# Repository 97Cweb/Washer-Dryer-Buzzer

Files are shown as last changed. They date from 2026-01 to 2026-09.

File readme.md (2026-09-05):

# Washer Dryer Buzzer

A thing to build to put buzzers back on the washing machine and dryer

V1 used a photoresistor on the washing machine
V2 uses 2 optocouplers to get the washing machine knob position.

Both use a non invasive current sensor for the dryer to get whether it is on or not.

You will also need a speaker module to get enough volume from the audio.

## Modules used:

* ARDUINO Nano 33 IOT

* 5PCS IR Infrared Slotted Optical Optocoupler Speed Measuring Sensor Module 3.3-5V for Arduino Also for Smart Robot Car Speed Measurement with Dupont Wire [Amazon](https://www.amazon.ca/dp/B09TK2H9NY)

* Non-Invasive Current Sensor (30A) [Canada Robotix](https://www.canadarobotix.com/products/246?variant=14423519297585)

* Stereo 20W Class D Audio Amplifier - MAX9744 [Adafruit 1752](https://www.adafruit.com/product/1752)

* 20W 4 Ohm Full Range Speaker - XS-GTF1027 [Adafruit 1732](https://www.adafruit.com/product/1732)

How to wire current sensor [link](https://www.engineersgarage.com/non-invasive-current-sensor-with-arduino/)

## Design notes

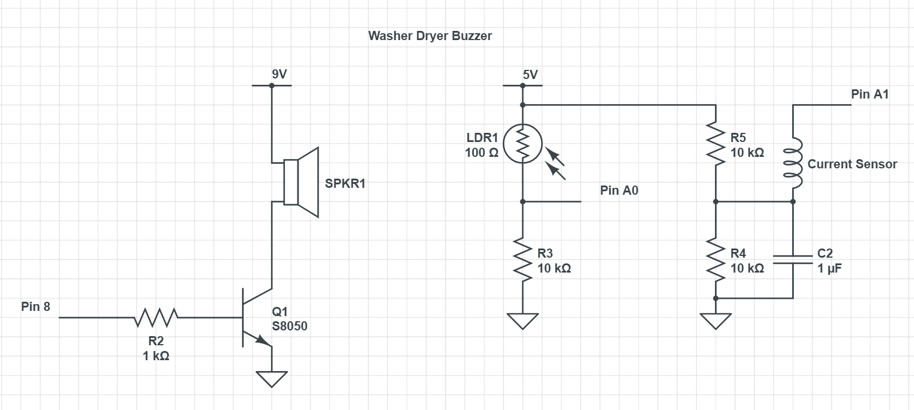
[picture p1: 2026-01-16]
washer dryer buzzer schematic.png

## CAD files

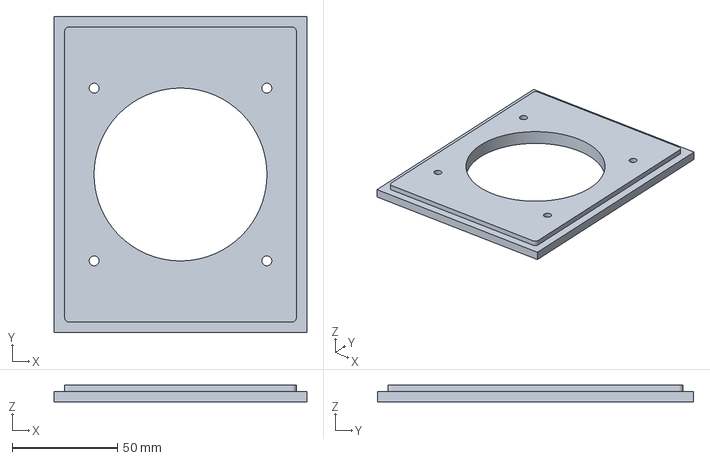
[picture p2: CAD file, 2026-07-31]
Box/lid-Body.3mf
120.0 x 150.0 x 8.00 mm

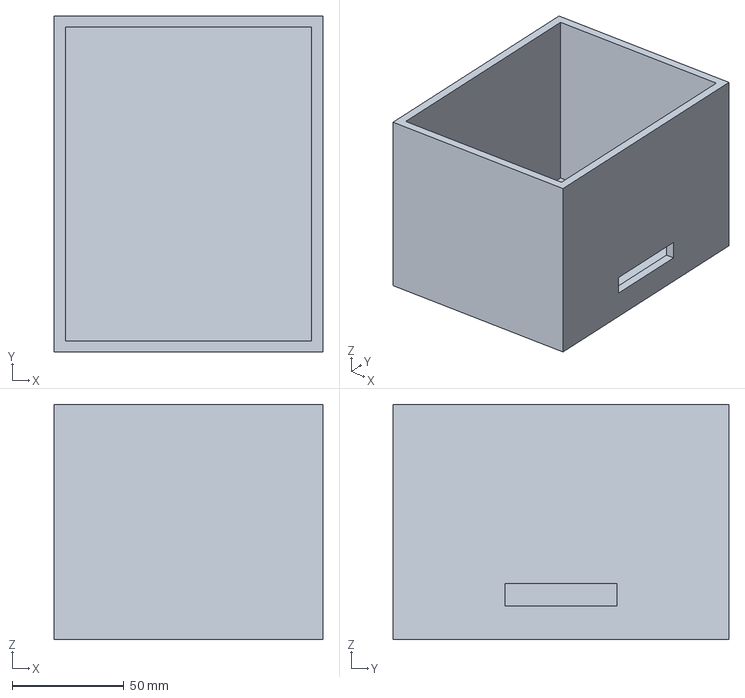
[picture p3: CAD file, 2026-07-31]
Box/box.FCStd
120.0 x 150.0 x 105.0 mm

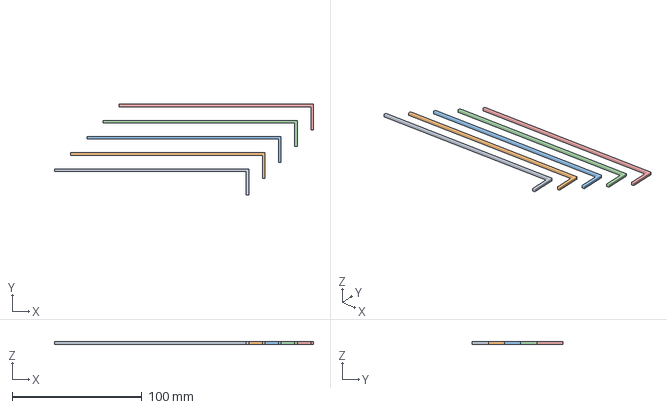
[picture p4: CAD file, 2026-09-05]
washer trip arm.3mf
200.0 x 70.0 x 2.00 mm

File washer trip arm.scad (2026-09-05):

difference(){
  cube([150,20,2]);
  cube([148,18,2]);
}

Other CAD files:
Box/lid.FCStd
Box/box-Body.3mf
washer trip arm.stl

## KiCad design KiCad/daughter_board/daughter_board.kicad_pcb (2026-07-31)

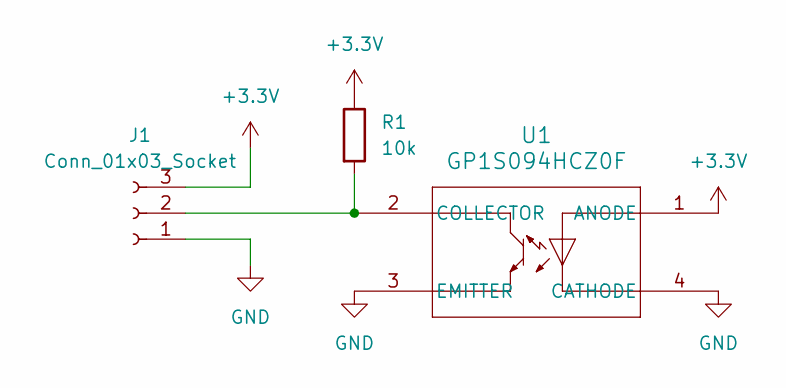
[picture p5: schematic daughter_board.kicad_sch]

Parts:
J1: Conn_01x03_Socket; JST_XA_B03B-XASK-1_1x03_P2.50mm_Vertical
R1: 10k; R_1206_3216Metric_Pad1.30x1.75mm_HandSolder
U1: GP1S094HCZ0F; TO_4HCZ0F_SHP

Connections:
+3.3V: J1.3, R1.1, U1.1 (ANODE)
GND: J1.1, U1.3 (EMITTER), U1.4 (CATHODE)
unnamed: J1.2, R1.2, U1.2 (COLLECTOR)

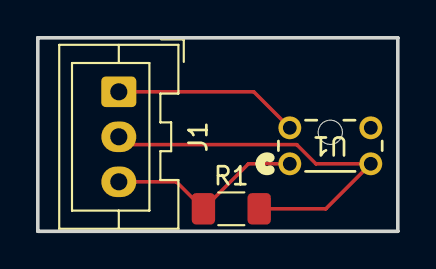
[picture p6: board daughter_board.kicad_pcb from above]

Board: 2 copper layers, 20.0 x 10.8 mm, 3 parts (0 on the bottom side), 3 nets.

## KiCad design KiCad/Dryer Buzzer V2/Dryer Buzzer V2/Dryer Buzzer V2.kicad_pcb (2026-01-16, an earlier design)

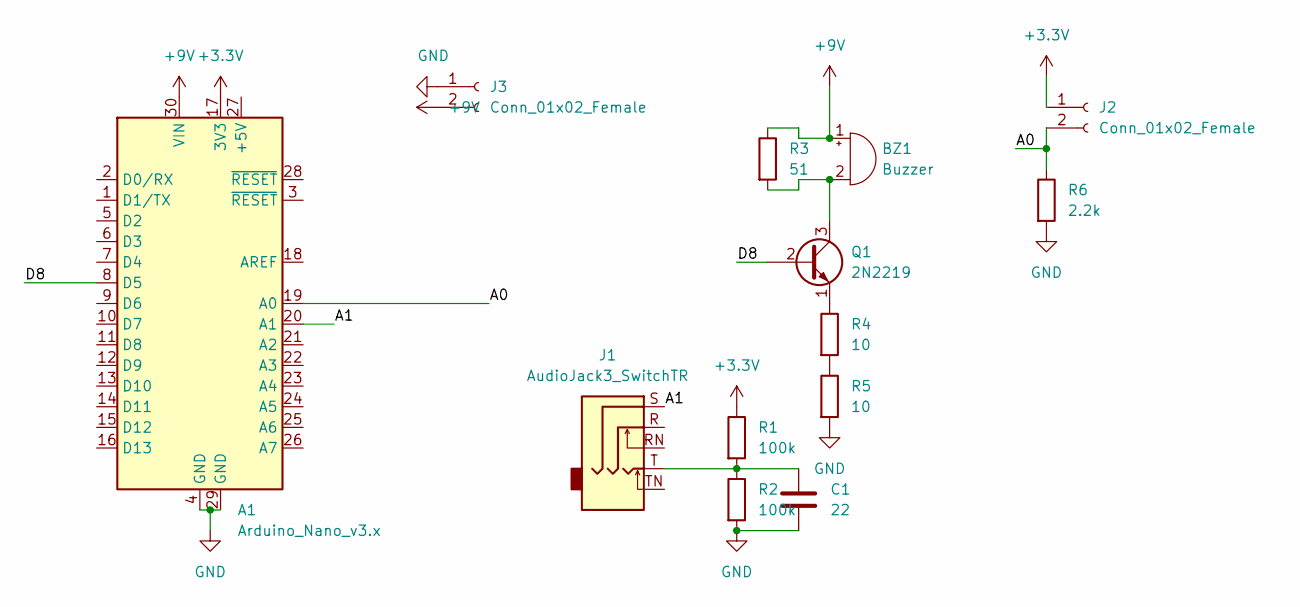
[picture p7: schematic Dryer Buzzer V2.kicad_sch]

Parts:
A1: Arduino_Nano_v3.x; Arduino_Nano
BZ1: Buzzer; Buzzer_12x9.5RM7.6
C1: 22; CP_Radial_D5.0mm_P2.50mm
J1: AudioJack3_SwitchTR; Jack_3.5mm_CUI_SJ1-3525N_Horizontal
J2, J3: Conn_01x02_Female; JST_EH_B2B-EH-A_1x02_P2.50mm_Vertical
Q1: 2N2219; TO-39-3
R1, R2: 100k; R_Axial_DIN0207_L6.3mm_D2.5mm_P10.16mm_Horizontal
R3: 51; R_Axial_DIN0207_L6.3mm_D2.5mm_P10.16mm_Horizontal
R4, R5: 10; R_Axial_DIN0207_L6.3mm_D2.5mm_P10.16mm_Horizontal
R6: 2.2k; R_Axial_DIN0207_L6.3mm_D2.5mm_P10.16mm_Horizontal

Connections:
+3V3: A1.17 (3V3), J2.1, R1.1
+9V: A1.30 (VIN), BZ1.1 (-), J3.2, R3.1
/A0: A1.19 (A0), J2.2, R6.1
/A1: A1.20 (A1), J1.S
/D8: A1.8 (D5), Q1.2 (B)
GND: A1.4 (GND), A1.29 (GND), C1.2, J3.1, R2.2, R5.2, R6.2
unnamed: BZ1.2 (+), Q1.3 (C), R3.2
unnamed: C1.1, J1.T, R1.2, R2.1
unnamed: Q1.1 (E), R4.1
unnamed: R4.2, R5.1

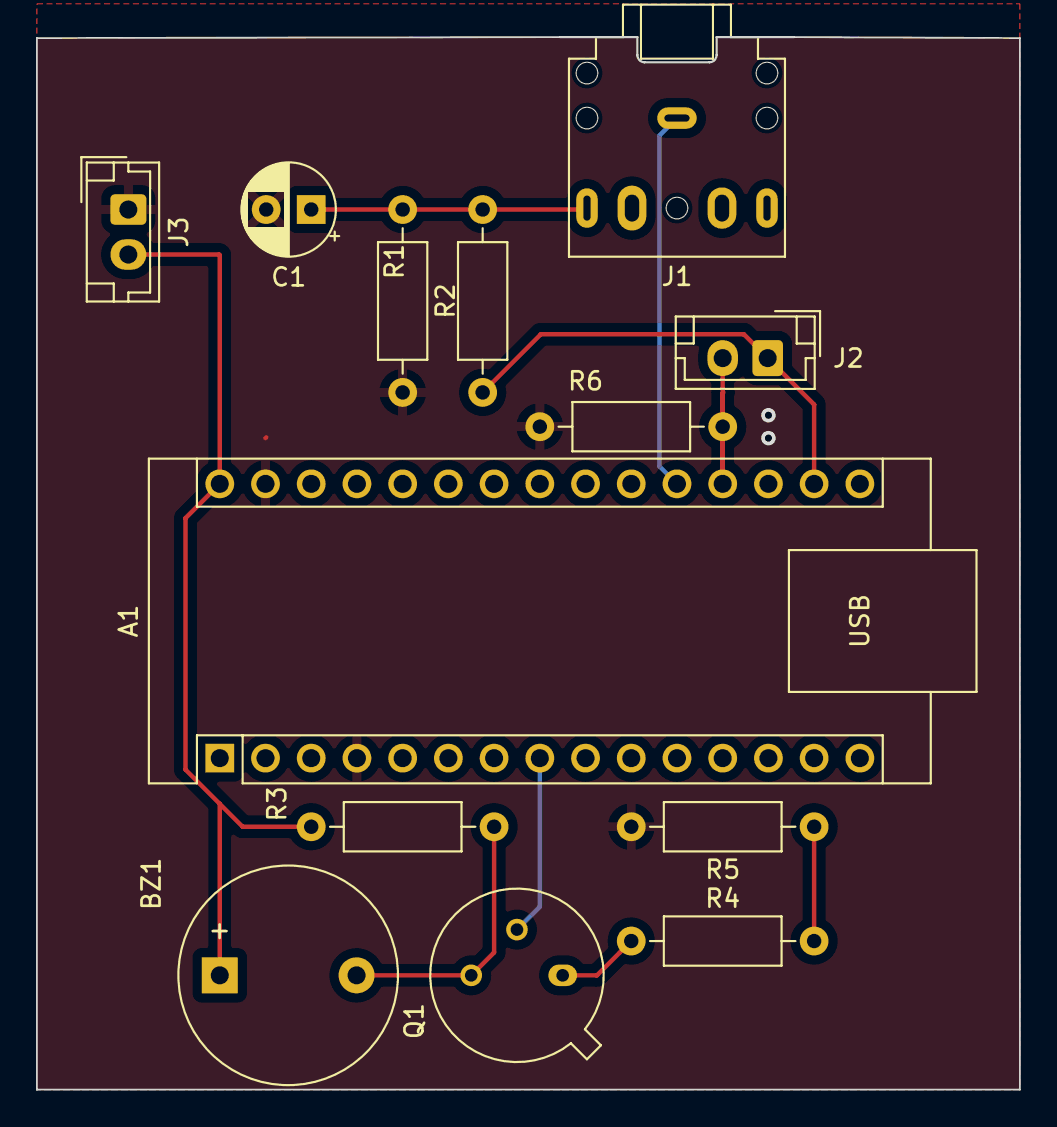
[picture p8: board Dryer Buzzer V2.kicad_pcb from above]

Board: 2 copper layers, 54.6 x 58.5 mm, 13 parts (0 on the bottom side), 10 nets.

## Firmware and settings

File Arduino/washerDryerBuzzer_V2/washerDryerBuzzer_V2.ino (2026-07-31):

//need to set serial to 1200 for upload to work

const bool DEBUG=true;
const int dryerSensorPin = A1;
const int washerNotHome1Pin = A2;
const int washerNotHome2Pin = A3;
const int resetPin = A4;
const int speakerPin = 5;

bool dryerOn=false;
bool washerOn = false;
bool dryerDone = false;
bool washerDone = false;


const int numVreadings=200;

int dryerReadingCount = 0;
float dryerSquareSum = 0;

bool dryerReadingReady = false;
bool latestDryerState = false;

unsigned long lastDryerSampleTime = 0;
const unsigned long dryerSampleInterval = 1;


unsigned long lastBeepTime = 0;
const unsigned long beepDuration = 2000;
const unsigned long beepInterval = 4000;

bool beepWasherNext = true;

  
void setup(){
  Serial.begin(9600);

  pinMode(washerNotHome1Pin, INPUT);
  pinMode(washerNotHome2Pin, INPUT);
  pinMode(resetPin,INPUT_PULLUP);

  Serial.println("Start");

}
void loop() {
  if (!digitalRead(resetPin)) {
    reset();
    return;
  }

  updateDryerSensor();
  updateDryer();
  updateWasher();
  updateBeeper();
}


void updateBeeper(){
  unsigned long now = millis();

  if (now - lastBeepTime < beepInterval){
    return;
  }

  if (washerDone && dryerDone){
    if(beepWasherNext){
      tone(speakerPin,640,beepDuration);
    }
    else{
      tone(speakerPin,512,beepDuration);
    }
    beepWasherNext = ! beepWasherNext;
    lastBeepTime = now;
  }
  else if (washerDone){
    tone(speakerPin,640,beepDuration);
    lastBeepTime = now;
  }
  else if (dryerDone){
    tone (speakerPin,512, beepDuration);
    lastBeepTime = now;
  }
}


void updateDryerSensor() {
  unsigned long now = millis();

  if (now - lastDryerSampleTime < dryerSampleInterval) {
    return;
  }

  lastDryerSampleTime = now;

  int reading = analogRead(dryerSensorPin);

  dryerSquareSum += sq((float)reading);
  dryerReadingCount++;

  if (dryerReadingCount >= numVreadings) {
    float rmsAvg = sqrt(dryerSquareSum / numVreadings);

    latestDryerState = rmsAvg > 200.0;
    dryerReadingReady = true;

    if (DEBUG) {
      Serial.println("RMS: " + String(rmsAvg));
    }

    dryerSquareSum = 0;
    dryerReadingCount = 0;
  }
}

void updateDryer() {
  if (!dryerReadingReady) {
    return;
  }

  dryerReadingReady = false;

  bool newDryerOn = latestDryerState;

  if (DEBUG) {
    Serial.println("Dryer " + String(newDryerOn));
  }

  if (dryerOn && !newDryerOn) {
    dryerDone = true;
    lastBeepTime = millis() - beepInterval;
  }

  dryerOn = newDryerOn;
}

void updateWasher(){
  bool washer1NotHome = digitalRead(washerNotHome1Pin); 
  bool washer2NotHome = digitalRead(washerNotHome2Pin);
  bool newWasherOn =  washer1NotHome && washer2NotHome;
  if (washerOn && !newWasherOn){
    washerDone = true;
    lastBeepTime = millis() - beepInterval;
    Serial.println("Washer done");
  }
  washerOn = newWasherOn;
}

void reset() {
  dryerDone = false;
  washerDone = false;

  noTone(speakerPin);
  Serial.println("reset");
  lastBeepTime = millis();
  beepWasherNext = true;
}

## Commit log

2026-07-31 buzzer v2 works
    [box-Body.3mf, box.FCStd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]
2026-09-05 add arduino module type
    [washer trip arm.3mf, washer trip arm.scad, washer trip arm.stl]
